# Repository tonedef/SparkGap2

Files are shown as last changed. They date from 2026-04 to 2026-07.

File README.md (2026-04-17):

# SparkGap2
This repo is for building the SparkGap2, a tube diode based overdrive guitar FX pedal, originally developed by Merlin Blencowe:
- [SparkGap2 design](https://valvewizard.co.uk/sparkgap.html)
- [Merlin's Website](https://www.valvewizard.co.uk/)
- [Merlin's Books](https://www.lulu.com/spotlight/valve_wizard)

v0.3 under releases is mostly tested and working with caveats. Still getting some noise that I'm debugging (like gain instead of clean pass-thru when the pedal is off). Latest version here is updated to fix those, but hasn't been fab'd yet to verify.

Feel free to contribute. Merlin's a great guy, and without a doubt in my mind the authority on valve designs. His books have taught me a lot not just about vacuum tube amplifiers and linear power supplies, but electronics in general. I can honestly say he's thourghly responsible for the thousands of dollars I've spent to become the proud owner of the tons of copper and glass that's currently occupying about a third of my garage and music studio in various forms of audio projects - the SparkGap2 will soon be among them. Thanks Merlin for your genius and all the fun it continues to bring!
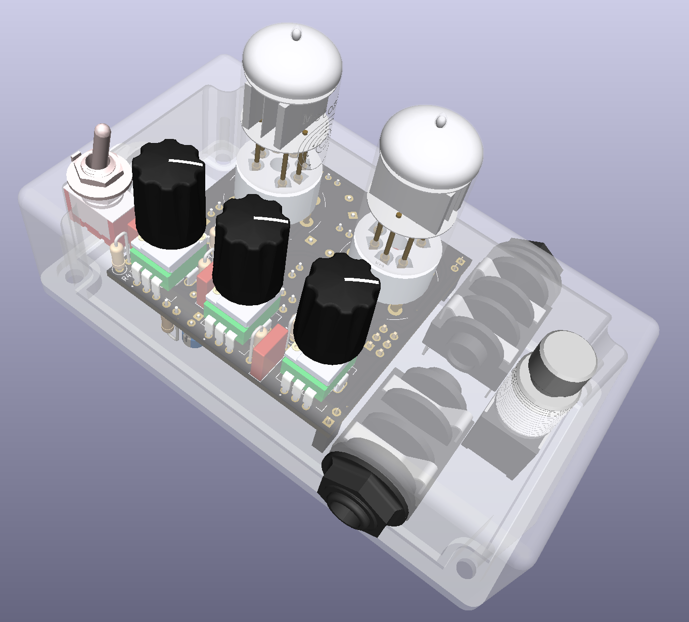
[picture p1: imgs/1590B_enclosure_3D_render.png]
SparkGap2 PCB render


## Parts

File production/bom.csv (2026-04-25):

Designator | Footprint | Quantity | Value | LCSC Part #
C1, C2 | C_Rect_L7.2mm_W2.5mm_P5.00mm_FKS2_FKP2_MKS2_MKP2 | 2 | 2.2n
C10, C4, C8 | C_Rect_L7.2mm_W2.5mm_P5.00mm_FKS2_FKP2_MKS2_MKP2 | 3 | 100n
C11, C13 | CP_Radial_D6.3mm_P2.50mm | 2 | 22u
C12, C14 | CP_Radial_D10.0mm_P5.00mm | 2 | 1000u
C3 | CP_Radial_D5.0mm_P2.00mm | 1 | 10u
C5, C7 | C_Rect_L7.2mm_W2.5mm_P5.00mm_FKS2_FKP2_MKS2_MKP2 | 2 | 4.7n
C6 | C_Rect_L7.2mm_W2.5mm_P5.00mm_FKS2_FKP2_MKS2_MKP2 | 1 | 470p
C9 | C_Rect_L7.2mm_W2.5mm_P5.00mm_FKS2_FKP2_MKS2_MKP2 | 1 | 33n
D1 | D_DO-41_SOD81_P2.54mm_Vertical_AnodeUp | 1 | 1N4001
D2, D3 | LED_D3.0mm | 2 | LED
D4 | D_DO-35_SOD27_P2.54mm_Vertical_AnodeUp | 1 | 1N4148
GAIN1, TONE1, VOL.1 | potentiometer_vert_no_switch | 3 | 10k
MOUNT1, MOUNT2 | B9A-shield-single-mount | 2 | B9A Mount
Q1 | TO-92_Inline_Wide | 1 | BS170
R1, R3 | R_Axial_DIN0207_L6.3mm_D2.5mm_P2.54mm_Vertical | 2 | 2.2M
R10, R14, R9 | R_Axial_DIN0207_L6.3mm_D2.5mm_P2.54mm_Vertical | 3 | 1k
R11, R13, R2, R5 | R_Axial_DIN0207_L6.3mm_D2.5mm_P2.54mm_Vertical | 4 | 100R
R12 | R_Axial_DIN0207_L6.3mm_D2.5mm_P2.54mm_Vertical | 1 | 33R
R4 | R_Axial_DIN0207_L6.3mm_D2.5mm_P2.54mm_Vertical | 1 | 2.2k
R6 | R_Axial_DIN0207_L6.3mm_D2.5mm_P2.54mm_Vertical | 1 | 4.7k
R7 | R_Axial_DIN0207_L6.3mm_D2.5mm_P7.62mm_Horizontal | 1 | 47k
R8 | R_Axial_DIN0207_L6.3mm_D2.5mm_P2.54mm_Vertical | 1 | 47k
U1 | DIP-8_W7.62mm_LongPads | 1 | TL072
V1, V2 | B7G (7 Pin Mini)-B9A-shield-mount | 2 | EB91

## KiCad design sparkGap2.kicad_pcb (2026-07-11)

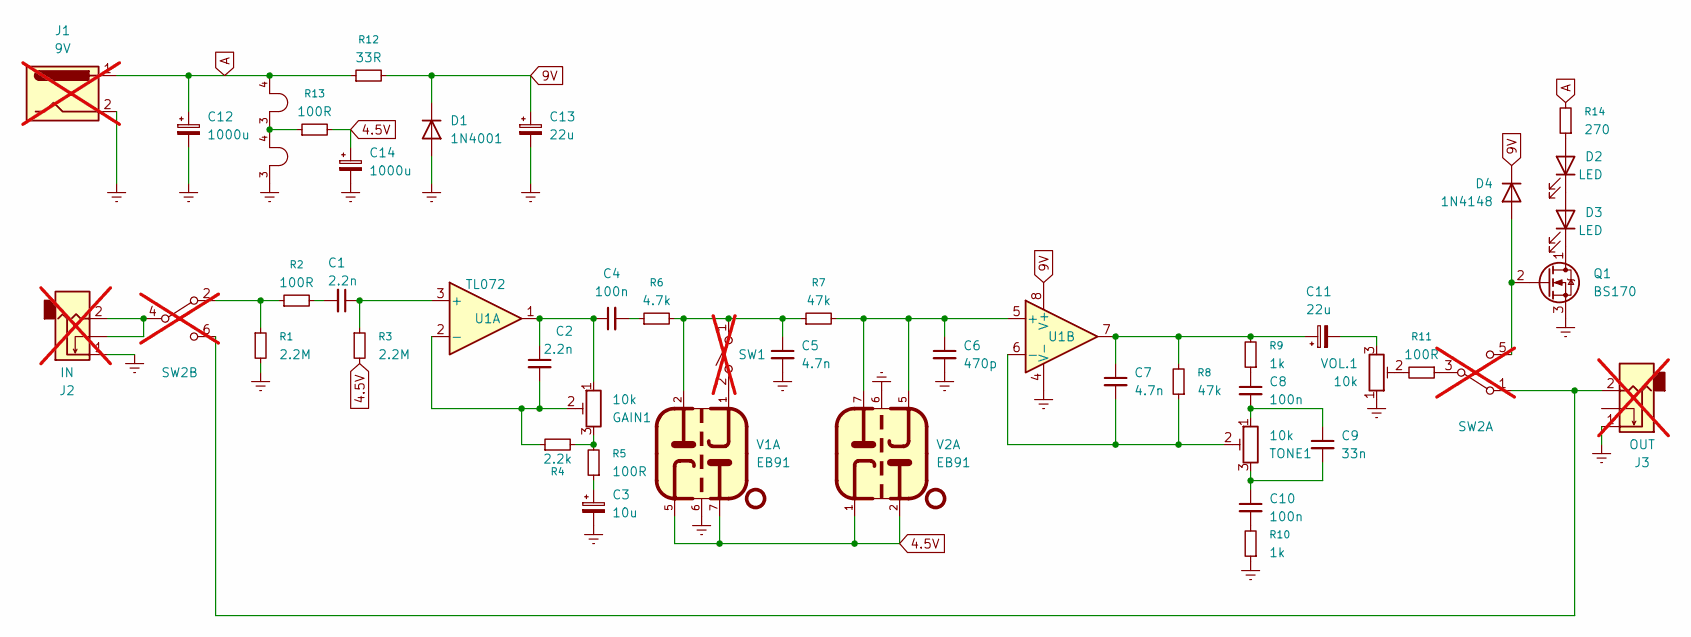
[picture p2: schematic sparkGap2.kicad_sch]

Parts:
C1, C2: 2.2n; C_Rect_L7.2mm_W2.5mm_P5.00mm_FKS2_FKP2_MKS2_MKP2; MFG Part B32529C1222K189
C3: 10u; CP_Radial_D5.0mm_P2.00mm; MFG Part EEU-FR1H100
C4, C8, C10: 100n; C_Rect_L7.2mm_W2.5mm_P5.00mm_FKS2_FKP2_MKS2_MKP2; MFG Part MKT1817410065
C5, C7: 4.7n; C_Rect_L7.2mm_W2.5mm_P5.00mm_FKS2_FKP2_MKS2_MKP2; MFG Part B32529C1472K000
C6: 470p; C_Rect_L7.2mm_W2.5mm_P5.00mm_FKS2_FKP2_MKS2_MKP2; MFG Part FKS2D004701A00JSSD
C9: 33n; C_Rect_L7.2mm_W2.5mm_P5.00mm_FKS2_FKP2_MKS2_MKP2; MFG Part B32529C0333K189
C11, C13: 22u; CP_Radial_D5.0mm_P2.00mm; MFG Part EEU-FR1H220
C12, C14: 1000u; CP_Radial_D10.0mm_P5.00mm; MFG Part 16PX1000MEFC10X12.5
D1: 1N4001; D_DO-41_SOD81_P2.54mm_Vertical_AnodeUp; MFG Part 1N4001RLG
D2, D3: LED; LED_D3.0mm; MFG Part BL-BJU3V1
D4: 1N4148; D_DO-35_SOD27_P2.54mm_Vertical_AnodeUp; MFG Part 1N4148-T50A
GAIN1: 10k; potentiometer_vert_no_switch; MFG Part RK09L1140A5L
J1: 9V; PinSocket_1x02_P2.54mm_Vertical; MFG Part 54-00151; not fitted
J2: IN; PinSocket_1x02_P2.54mm_Vertical; MFG Part NMJ4HC-S; not fitted
J3: OUT; PinSocket_1x02_P2.54mm_Vertical; MFG Part NMJ4HC-S; not fitted
Mount1, Mount2: B9A Mount; B9A-shield-single-mount; MFG Part 971100354
Q1: BS170; TO-92_Inline_Wide; MFG Part BS170
R1, R3: 2.2M; R_Axial_DIN0207_L6.3mm_D2.5mm_P2.54mm_Vertical
R2, R5, R11, R13: 100R; R_Axial_DIN0207_L6.3mm_D2.5mm_P2.54mm_Vertical
R4: 2.2k; R_Axial_DIN0207_L6.3mm_D2.5mm_P2.54mm_Vertical
R6: 4.7k; R_Axial_DIN0207_L6.3mm_D2.5mm_P2.54mm_Vertical
R7: 47k; R_Axial_DIN0207_L6.3mm_D2.5mm_P7.62mm_Horizontal
R8: 47k; R_Axial_DIN0207_L6.3mm_D2.5mm_P2.54mm_Vertical
R9, R10: 1k; R_Axial_DIN0207_L6.3mm_D2.5mm_P2.54mm_Vertical
R12: 33R; R_Axial_DIN0207_L6.3mm_D2.5mm_P2.54mm_Vertical
R14: 270; R_Axial_DIN0207_L6.3mm_D2.5mm_P2.54mm_Vertical
SW1: SPST; PinSocket_1x02_P2.54mm_Vertical; MFG Part SW-T3-1A-A-A3-S1; not fitted
SW2: 6-pin Footswitch; PinHeader_2x03_P2.54mm_Vertical; MFG Part SF12020DF; not fitted
TONE1: 10k; potentiometer_vert_no_switch; MFG Part RK09L1140A5L
U1: TL072; DIP-8_W7.62mm_LongPads; MFG Part TL072IP
V1, V2: EB91; B7G (7 Pin Mini)-B9A-shield-mount
VOL.1: 10k; potentiometer_vert_no_switch; MFG Part RK09L1140A5L

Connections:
4.5V: C14.1, R3.2, R13.2, V1.5, V1.7, V2.1, V2.2
9V: C13.1, D1.1 (K), D4.1 (K), R12.2, U1.8 (V+)
A: C12.1, J1.1, R12.1, R14.2, V1.4
Earth: C3.2, C5.2, C6.2, C12.2, C13.2, C14.2, D1.2 (A), J1.2, J2.1, J3.1, Q1.3 (S), R1.2, R10.1, U1.4 (V-), V1.6, V2.3, V2.6, VOL.1.1
unnamed: C1.2, R2.2
unnamed: C2.1, C4.1, GAIN1.1, U1.1
unnamed: C3.1, R5.1
unnamed: C4.2, R6.1
unnamed: C8.1, R9.1
unnamed: C8.2, C9.1, TONE1.1
unnamed: C9.2, C10.1, TONE1.3
unnamed: C10.2, R10.2
unnamed: C7.1, C11.1, R8.2, R9.2, U1.7
unnamed: C11.2, VOL.1.3
unnamed: D2.2 (A), R14.1
unnamed: D2.1 (K), D3.2 (A)
unnamed: D3.1 (K), Q1.1 (D)
unnamed: D4.2 (A), Q1.2 (G), SW2.5
unnamed: GAIN1.3, R4.2, R5.2
unnamed: J2.2, SW2.4
unnamed: J3.2, SW2.1, SW2.6
unnamed: R1.1, R2.1, SW2.2
unnamed: R11.1, SW2.3
unnamed: R11.2, VOL.1.2
unnamed: R13.1, V1.3, V2.4
unnamed: C5.1, R6.2, R7.1, SW1.1 (A), V1.2
unnamed: SW1.2 (B), V1.1
unnamed: C1.1, R3.1, U1.3 (+)
unnamed: C2.2, GAIN1.2, R4.1, U1.2 (-)
unnamed: C6.1, R7.2, U1.5 (+), V2.5, V2.7
unnamed: C7.2, R8.1, TONE1.2, U1.6 (-)

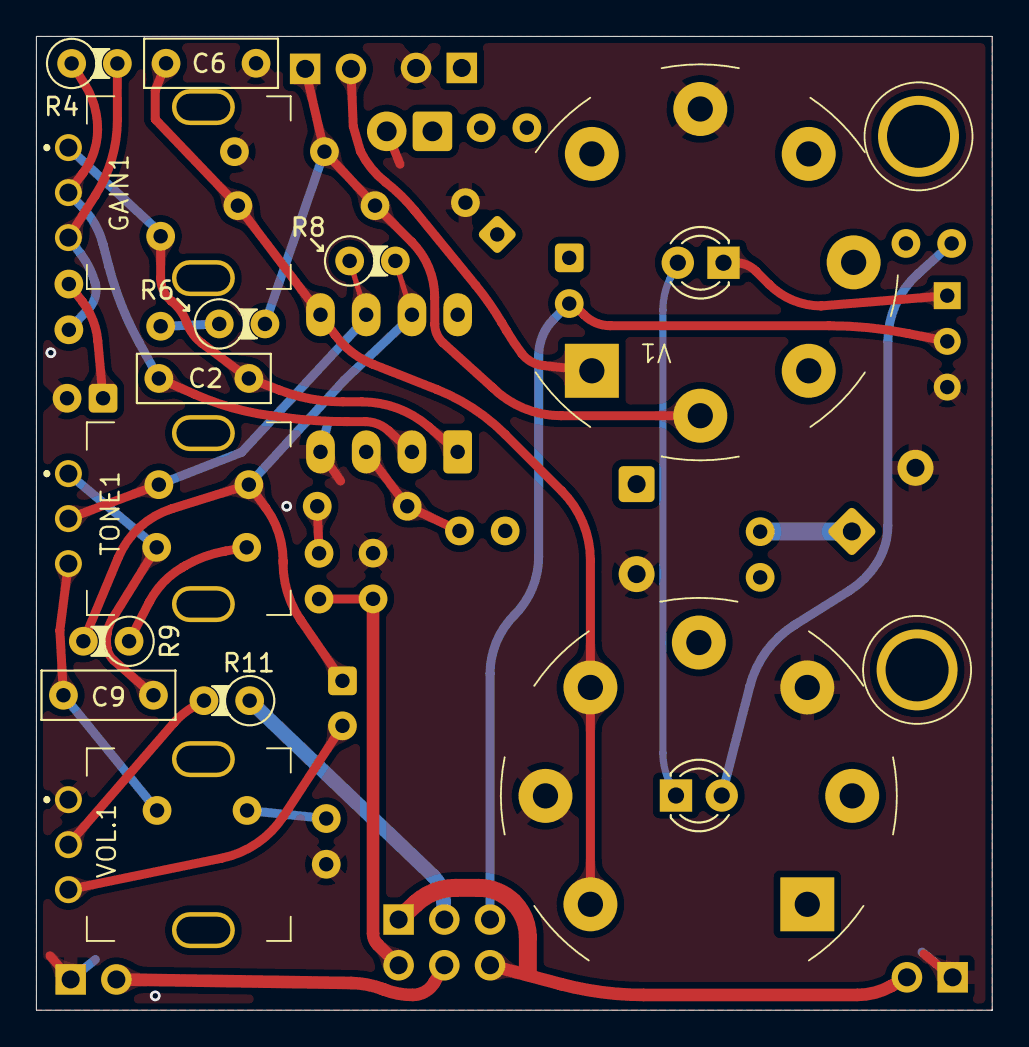
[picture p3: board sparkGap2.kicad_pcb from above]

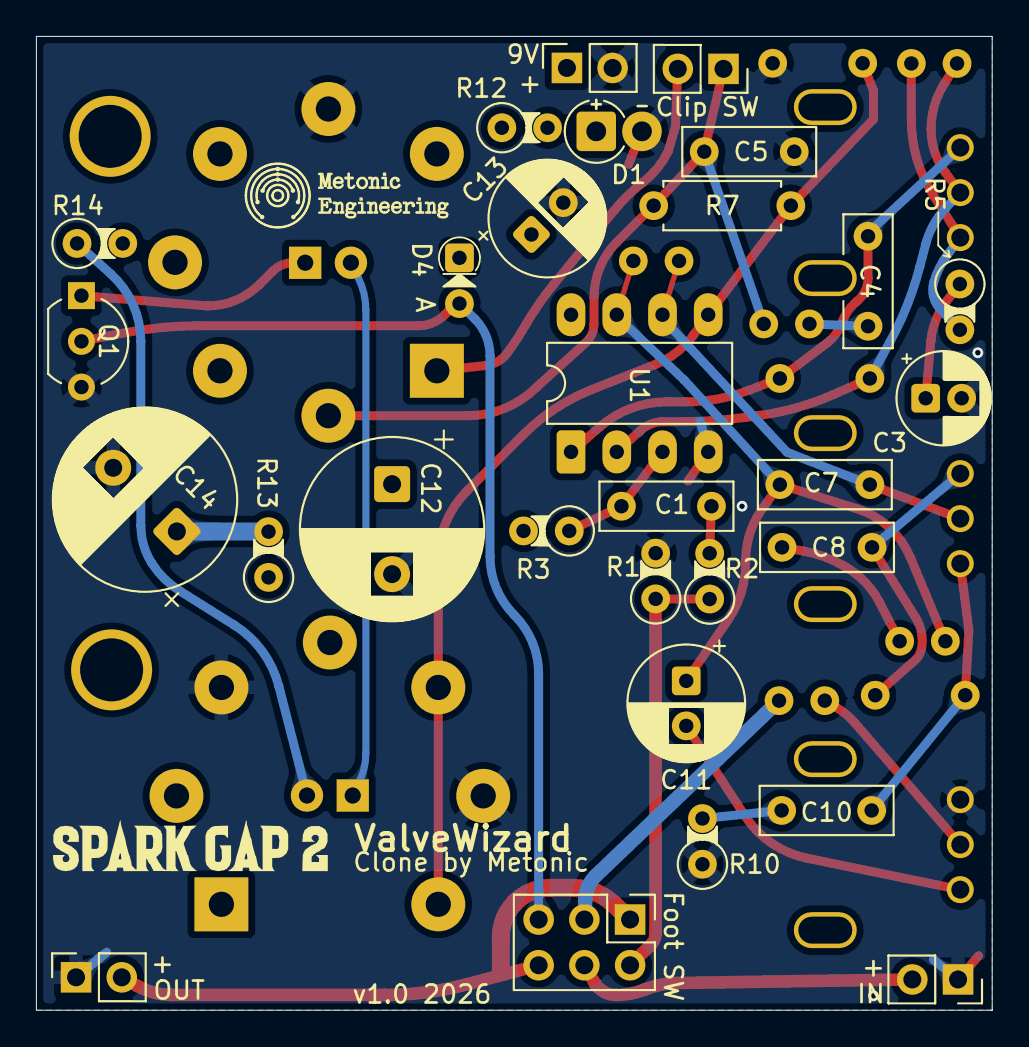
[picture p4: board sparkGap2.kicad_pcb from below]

Board: 4 copper layers, 53.1 x 54.1 mm, 46 parts (29 on the bottom side), 31 nets.

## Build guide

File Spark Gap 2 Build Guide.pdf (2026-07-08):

# Spark Gap 2 Build Guide

TLDR;

Dry fit everything before drilling/cutting or soldering anything. When soldering, pots, B7G sockets, and wires that connect to "off board" stuff go last.

### 1. Ordering:

a. Components from the bom.csv (https://github.com/tonedef/SparkGap2/blob/master/production/bom.csv) in the production folder: Note the footprints to ensure you get the right size (e.g. CP_Radial_D5.0mm_P2.00mm is a 5mm diameter cap with a 2mm pitch between leads).
b. Tubes (eBay, (https://www.ebay.com/sch/i.html?_nkw=EB91) Tube Depot, (https://tubedepot.com/) Tubes-Store): (https://tubes-store.com/)
i. 2x EB91/6AL5 tubes These don't need to be "matched"
ii. 2x B7G PCB mount sockets (7 pin minis)
c. 1x threaded, DC 5.5mm x 2.1mm jack. Make sure it's one where the case is isolated from the sleeve (e.g. plastic) since 9V pedal power supplies have the + terminal on the sleeve and gnd on the pin. You don't want to short the + to the case.
d. 2x TR jacks (or TRS). At least one must have a built-in switch, like a Neutrik nmj4hc-s (https://www.neutrik.com/en/product/nmj4hc-s)
e. 2x M3 10mm standoffs
f. 1x 6 pin footswitch.
g. A 1590B Hammond enclosure or larger (literally no dimension, h/w/l, should smaller or else things won't fit). If you're not super comfortable with machining the enclosure tightly, a 1590N1 will be more forgiving on placement errors, with roughly the same profile.
2. Machining enclosure face. Use the enclosure layout (https://github.com/tonedef/SparkGap2/blob/master/imgs/1590B_enclosure_layout.svg) or the C2D (https://github.com/tonedef/SparkGap2/blob/master/CNC/1590B_enclosure_face.c2d) file to CNC the top of your enclosure. (http://enclosure.or) Or, to manually create (practicing on scrap wood first is a good idea, if you're unsure):
a. Print out the enclosure layout. (https://github.com/tonedef/SparkGap2/blob/master/imgs/1590B_enclosure_layout.svg) Ensure it's to scale by lining up the PCB to the printout
b. Cut the printout to fit the enclosure, ensure the layout is well centered and flat with no buckling and tape it down. There's very little wiggle room side to side, and not much more top to bottom, so really check this
c. Use a center punch, or stainless steel nail to tap the center of all the drill holes for which you have bit large enough for
d. For the remaining holes, using a sharp tool edge, or the tip of a bit, and trace firmly over the outline of the holes
e. Remove the printout and Drill/cut holes
3. Machining enclosure sides. The same enclosure layout has three lines sticking out marking the positions of the holes for the DC power and TR jacks
i. Mark the enclosure on the face plate at these points
ii. | Draw a vertical line down the sides of the of the enclosure at these points
iii. | Lay your jacks next to these, and mark their centers on the line. You basically want to
| ensure the jacks have enough room inside the enclosure so
1. you can screw in the bottom of the enclosure
2. They don't short out on either the bottom of the enclosure or the top

iv. | Before drilling the sides, place the PCB inside the enclosure and line it up, then lay in
| your jacks inside as well, and make sure they fit where you've marked, then remove
| everything from the enclosure
v. Use a center punch to mark the hole centers and drill
4. Assemble step. Follow this order to minimize issues:
a. Install all resistors. Most are placed vertically to save space
b. Install all film caps (i.e. everything but the electrolytics)
c. Install potentiometers (note that you will have to squeeze between caps in some places)
d. Install IC, MOSFET, and Diodes
e. Install the electrolytics
f. Place the LEDs, but don't solder them yet
g. Install the 7-pin PCB mount sockets (aka B7G socket)
h. Push each LED up into the 7-pin socket. Make sure it doesn't protrude from the top of the socket (usually not a problem since the LED's base is wider than the socket's hole). Solder in place.
i. Jumper the tip to sleeve on the switch side of the input jack
j. Wire the symmetry switch. Wire should be long to ensure the switch can fit with some space above the "Gain" potentiometer
k. Wire the jacks to the board
i. Jacks should face opposite directions
ii. | Make sure there's enough wire so that the jacks can be rotated to fit within the
| enclosure without shorting to it
l. Wire the footswitch to the board
i. Wires should be just long enough that the switch can clear the jacks without tension,
| again, lay stuff out physically and check
ii. | Pay careful attention to the schematic to avoid mis-wiring it
m. Strongly suggest you make the DC jack "pluggable" to the PCB, so you can completely disassemble the pedal. If you do, wire up the DC jack now and test. If you don't, then wait till you finish the rest of the assembly.
n. Loosely attach 10mm standoffs to the PCB
o. If your TR jacks are isolated (like the nmj4hc-s), solder a wire to the sleeve pin of the input jack, and solder the other end to a washer or locking washer that'll fit over the jack to use as the main ground point.
p. Dry fit everything into the pedal board. If something doesn't fit, adjust the enclosure accordingly, don't screw anything in yet.
q. If you didn't make the DC jack pluggable as suggested above, attach the DC plug, and solder it to the board and test.
r. Screw everything in. Done!

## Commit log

2025-12-13 Fix image link for SparkGap2 PCB render
    Updated image link for SparkGap2 PCB render to use GitHub's blob URL format.
2026-01-07 Add missing current limit resistor
    [sparkGap2.kicad_pcb, sparkGap2.kicad_sch]
2026-01-07 Improve gnd routing and gfx
    [bom.csv, designators.csv, positions.csv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]
2026-01-25 correct version info
    [sparkGap2.kicad_pcb]
2026-01-28 Fix schematic errors. Renumber to match ValveWizard schematic. Improve layout. Switch to 4 layer
    [bom.csv, designators.csv, positions.csv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]
2026-01-29 Tweak PCB layout. Add enclosure drill template and GFX. Delete unused backups
    [bom.csv, designators.csv, positions.csv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]
2026-02-02 move mount holes to 60 deg.
    [positions.csv, sparkGap2.kicad_pcb]
2026-03-15 Slight adjustments to layout. Clean up component numbering.
    [bom.csv, designators.csv, positions.csv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]
2026-04-14 add back mount holes
    [designators.csv, sparkGap2.kicad_pcb]
2026-04-16 bump ver.
    [sparkGap2.kicad_pcb]
2026-04-16 Address issues found with last production run
    [positions.csv, sparkGap2.kicad_pcb, sparkGap2.kicad_sch]
2026-04-16 add build guide, improve BOM, gen production
    [bom.csv, sparkGap2.kicad_pcb, sparkGap2.kicad_sch]
2026-04-17 Update SVG, CNC files. Improve traces around pots
    [positions.csv, sparkGap2.kicad_pcb, sparkGap2.kicad_sch]
2026-04-17 Clean up footprints and schematic to get rid of warnings
    [sparkGap2.kicad_pcb, sparkGap2.kicad_sch]
2026-04-20 update to KiCad v10
    [sparkGap2.kicad_pcb, sparkGap2.kicad_sch]
2026-04-25 Improve layout to aid in construction, better signal routing, and more visually appealing shield/PCB mounts
    [bom.csv, designators.csv, positions.csv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]
2026-07-08 Cleaner PCB layout. Better CNC placement. Added cut guides for pedal sides. Updated build guide.
    [sparkGap2.kicad_sch]
2026-07-08 Generate production files
    [sparkGap2.kicad_pcb]
2026-07-08 Tweak R placement under vol. pot. Round a few tracks
    [positions.csv, sparkGap2.kicad_pcb]
2026-07-11 improved silkscreen, and component refs
    [sparkGap2.kicad_pcb]
